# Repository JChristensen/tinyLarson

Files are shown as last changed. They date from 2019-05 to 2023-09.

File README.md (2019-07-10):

# Tiny Larson Scanner
https://github.com/JChristensen/tinyLarson  
README file  
Jack Christensen  
May-2019

## License
  
Tiny Larson Scanner by Jack Christensen is licensed under a [Creative Commons Attribution-ShareAlike 4.0 International License](http://creativecommons.org/licenses/by-sa/4.0/).

## Overview
This is just a fun project which is designed to utilize remaining capacity in old batteries while adding some decorative [Blinkenlights](https://en.wikipedia.org/wiki/Blinkenlights) to your shop or office.

Many battery-powered devices complain of low battery when there is still significant usable capacity left in the cells. Such cells can often power this circuit for many days or even a few weeks as the circuit only requires a few milliamperes and utilizes a boost regulator to maintain a constant supply voltage.

The circuit board fits on a dual AA cell holder and also has screw terminals for connection to other sources of power.

For more information, see the [firmware here](https://github.com/JChristensen/larson84).  
PC boards can be ordered from [OSH Park](https://oshpark.com/shared_projects/H8Wv3avv).  
A bill of materials is available at [Mouser Electronics](https://www.mouser.com/ProjectManager/ProjectDetail.aspx?AccessID=ef0590339b) and also in this repo.  

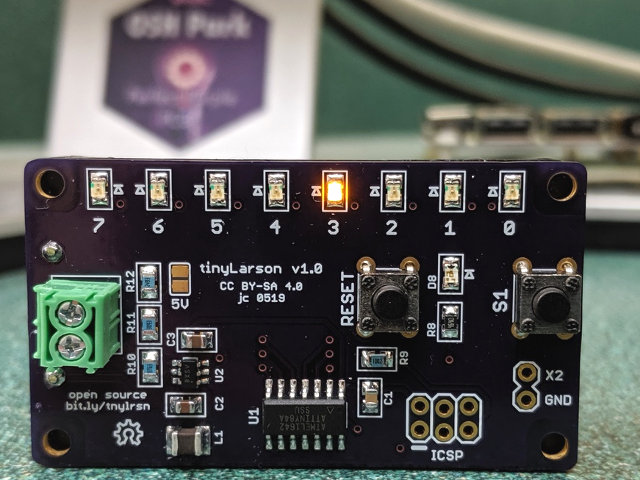
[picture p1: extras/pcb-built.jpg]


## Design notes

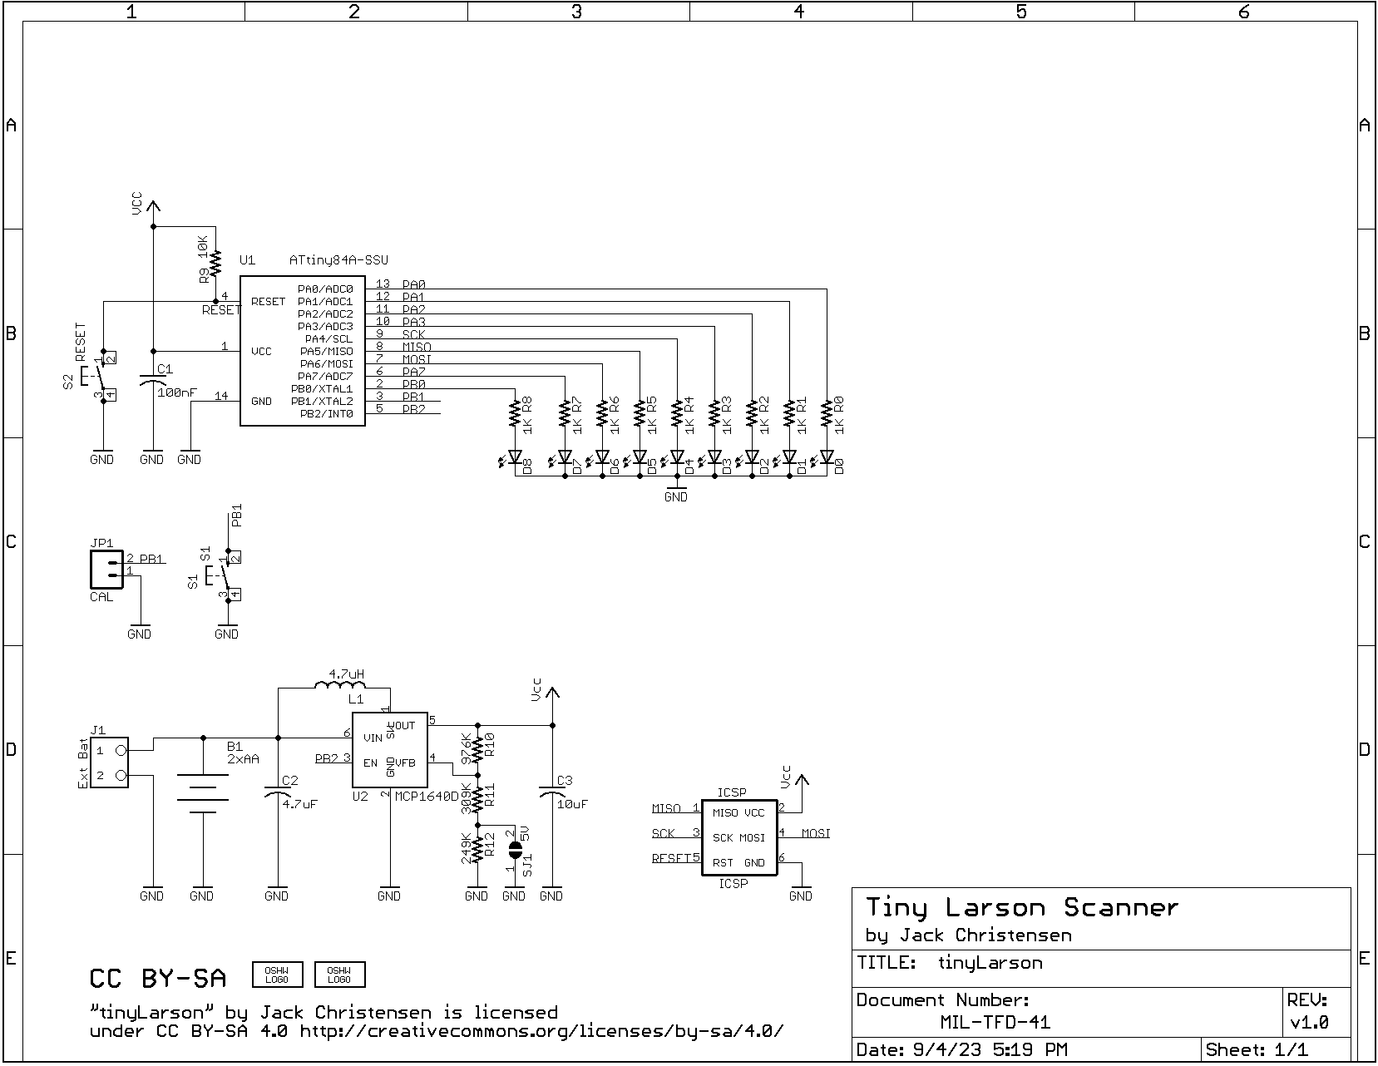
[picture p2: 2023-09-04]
schematic.png

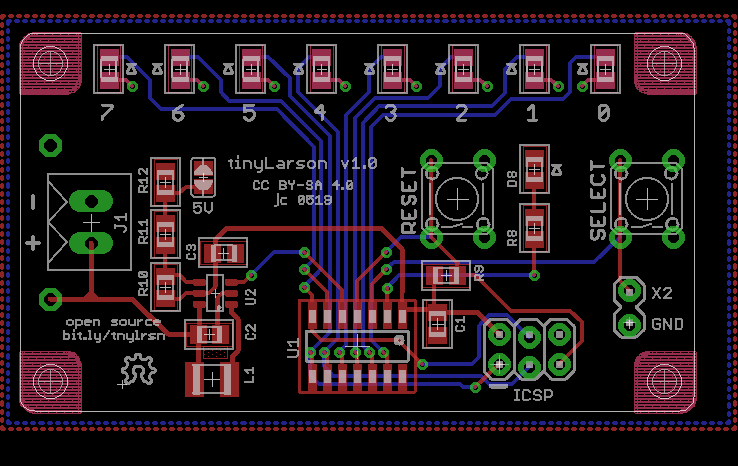
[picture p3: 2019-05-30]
board.png

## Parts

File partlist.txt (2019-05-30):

Partlist

Exported from tinyLarson.sch at 5/30/2019 3:46 PM

EAGLE Version 7.5.0 Copyright (c) 1988-2015 CadSoft

Assembly variant: 

Part     Value          Device                Package           Library  Sheet

B1       2xAA           BATTERY-2AAEAGLE      EAGLE-12BH321P-GR _jc      1
C1       100nF          C-USM0805             M0805             _jc      1
C2       4.7uF          C-USM0805             M0805             _jc      1
C3       10uF           C-USM0805             M0805             _jc      1
D0       Yel            LEDD0805A             D0805A            _jc      1
D1       Yel            LEDD0805A             D0805A            _jc      1
D2       Yel            LEDD0805A             D0805A            _jc      1
D3       Yel            LEDD0805A             D0805A            _jc      1
D4       Yel            LEDD0805A             D0805A            _jc      1
D5       Yel            LEDD0805A             D0805A            _jc      1
D6       Yel            LEDD0805A             D0805A            _jc      1
D7       Yel            LEDD0805              D0805             _jc      1
D8       Red            LEDD0805              D0805             _jc      1
ICSP     ICSP           AVR_SPI_PRG_62X3_LOCK 2X3_LOCK          _jc      1
J1       Ext Bat        OST-TB-23.5MM         OST-TB-2-3.5MM    _jc      1
JP1      CAL            M02LOCK               1X02_LOCK         SparkFun 1
L1       4.7uH          INDUCTORC1210K        C1210K            _jc      1
R0       1K             R-US_M0805            M0805             _jc      1
R1       1K             R-US_M0805            M0805             _jc      1
R2       1K             R-US_M0805            M0805             _jc      1
R3       1K             R-US_M0805            M0805             _jc      1
R4       1K             R-US_M0805            M0805             _jc      1
R5       1K             R-US_M0805            M0805             _jc      1
R6       1K             R-US_M0805            M0805             _jc      1
R7       1K             R-US_M0805            M0805             _jc      1
R8       1K             R-US_M0805            M0805             _jc      1
R9       10K            R-US_M0805            M0805             _jc      1
R10      976K           R-US_M0805            M0805             _jc      1
R11      309K           R-US_M0805            M0805             _jc      1
R12      249K           R-US_M0805            M0805             _jc      1
S1       S1             10-XXOCT              B3F-10XXOCT       _jc      1
S2       RESET          10-XXOCT              B3F-10XXOCT       _jc      1
SJ1      5V             SJ                    SJ                jumper   1
U1       ATtiny84A-SSU  ATTINYX4SO14          SO14              _jc      1
U2       MCP1640D       MCP1640               SOT23-6           _jc      1

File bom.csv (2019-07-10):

Bill of Materials
Tiny Larson Scanner
by Jack Christensen
May-2019
https://www.mouser.com/ProjectManager/ProjectDetail.aspx?AccessID=ef0590339b
Part | Qty | Mouser # | Description | Mfr. # | Manufacturer
B1 | 1 | 12BH321P-GR | Cylindrical Battery Contacts, Clips, Holders & Springs 2 "AA" PC LEADS BLK | 12BH321P-GR | Eagle Plastic Devices
C1 | 1 | 581-08053C104K | Multilayer Ceramic Capacitors MLCC - SMD/SMT 25V .1uF X7R 0805 10%TOL | 08053C104KAT2A | AVX
C2 | 1 | 963-EMK212ABJ475KG-T | Multilayer Ceramic Capacitors MLCC - SMD/SMT 0805 16VDC 4.7uF 10% X5R | EMK212ABJ475KG-T | Taiyo Yuden
C3 | 1 | 963-LMK212BJ106KG-T | Multilayer Ceramic Capacitors MLCC - SMD/SMT 10uF 10V X5R +/-10% 0805 Gen Purp | LMK212BJ106KG-T | Taiyo Yuden
D0-D7 | 8 | 859-LTST-C171KSKT | Standard LEDs - SMD Yellow Clear 587nm | LTST-C171KSKT | Lite-On
D8 | 1 | 859-LTST-C171KRKT | Standard LEDs - SMD Red Clear 55MCD | LTST-C171KRKT | Lite-On
J1 | 1 | 651-1984617 | Fixed Terminal Blocks PT 1.5/2-3.5H 2POS HRZ 3.5mm SCREW | 1984617 | Phoenix Contact
L1 | 1 | 963-CBC3225T4R7MR | Fixed Inductors 1210 4.7uH 130mOhms +/-20% 1010mA HiCur | CBC3225T4R7MR | Taiyo Yuden
R0-R8 | 9 | 603-RC0805FR-071KL | Thick Film Resistors - SMD 1K OHM 1% | RC0805FR-071KL | Yageo
R10 | 1 | 660-RK73H2ATTD9763F | Thick Film Resistors - SMD 1/4W 976K OHM 1% | RK73H2ATTD9763F | KOA Speer
R11 | 1 | 660-RK73H2ATTD3093F | Thick Film Resistors - SMD 1/4W 309K OHM 1% | RK73H2ATTD3093F | KOA Speer
R12 | 1 | 660-RK73H2ATTD2493F | Thick Film Resistors - SMD 1/4W 249K OHM 1% | RK73H2ATTD2493F | KOA Speer
R9 | 1 | 603-RC0805FR-1310KL | Thick Film Resistors - SMD 10K OHM 1% | RC0805FR-1310KL | Yageo
S1-S2 | 2 | 653-B3F-1020 | Tactile Switches 6X6 Flat 5mm Btn Force 100g w/o Grd | B3F-1020 | Omron
U1 | 1 | 556-ATTINY84A-SSU | 8-bit Microcontrollers - MCU 20MHz Ind. Grade | ATTINY84A-SSU | Microchip
U2 | 1 | 579-MCP1640DT-I/CHY | Switching Voltage Regulators 500 kHz 300 mA Syn Boost Converter | MCP1640DT-I/CHY | Microchip

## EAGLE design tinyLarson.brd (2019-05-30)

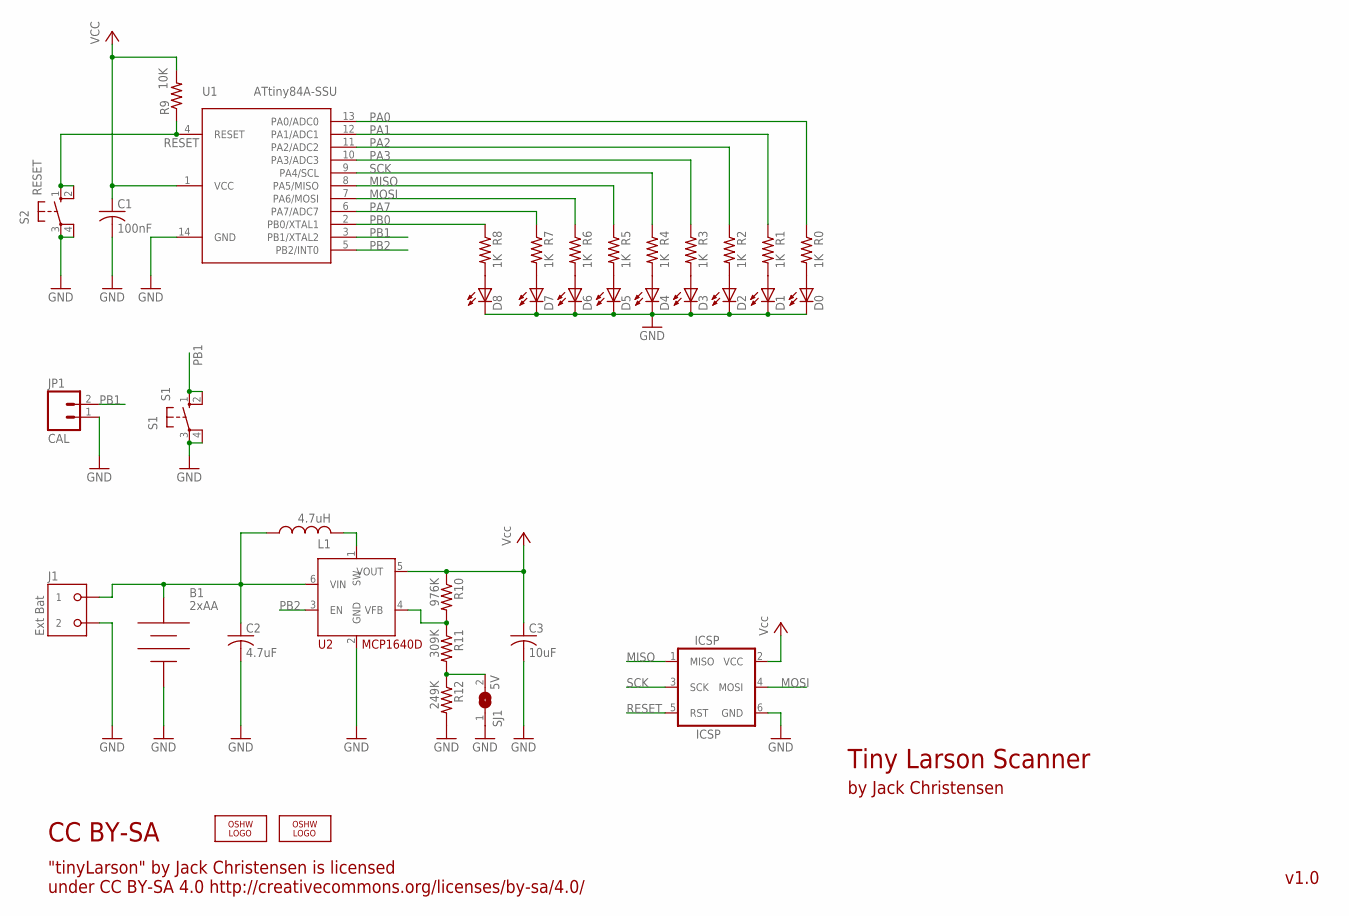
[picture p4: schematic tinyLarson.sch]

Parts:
B1: 2xAA; EAGLE-12BH321P-GR
C1: 100nF; M0805
C2: 4.7uF; M0805
C3: 10uF; M0805
D0, D1, D2, D3, D4, D5, D6: Yel; D0805A
D7: Yel; D0805
D8: Red; D0805
ICSP: ICSP; 2X3_LOCK
J1: Ext Bat; OST-TB-2-3.5MM
JP1: CAL; 1X02_LOCK
L1: 4.7uH; C1210K
LOGO1, LOGO2: OSHW_LOGO_8MILX0100-NT; OSHW_8X100_NOTEXT
R0, R1, R2, R3, R4, R5, R6, R7, R8: 1K; M0805
R9: 10K; M0805
R10: 976K; M0805
R11: 309K; M0805
R12: 249K; M0805
S1: S1; B3F-10XXOCT
S2: RESET; B3F-10XXOCT
SJ1: 5V; SJ
U1: ATtiny84A-SSU; SO14
U2: MCP1640D; SOT23-6

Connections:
GND: B1.NEG, C1.2, C2.2, C3.2, D0.K (C), D1.K (C), D2.K (C), D3.K (C), D4.K (C), D5.K (C), D6.K (C), D7.K (C), D8.K (C), ICSP.6 (GND), J1.P$2 (2), JP1.1, R12.2, S1.3, S1.4 (P1), S2.3, S2.4 (P1), SJ1.1, U1.14 (GND), U2.2 (GND)
MISO: ICSP.1 (MISO), R5.1, U1.8 (PA5/MISO)
MOSI: ICSP.4 (MOSI), R6.1, U1.7 (PA6/MOSI)
unnamed: R11.2, R12.1, SJ1.2
unnamed: R10.2, R11.1, U2.4 (VFB)
unnamed: D0.A, R0.2
unnamed: D1.A, R1.2
unnamed: D2.A, R2.2
unnamed: D3.A, R3.2
unnamed: L1.2, U2.1 (SW)
unnamed: D4.A, R4.2
unnamed: D5.A, R5.2
unnamed: D6.A, R6.2
unnamed: B1.POS, C2.1, J1.P$1 (1), L1.1, U2.6 (VIN)
unnamed: D7.A, R7.2
unnamed: D8.A, R8.2
PA0: R0.1, U1.13 (PA0/ADC0)
PA1: R1.1, U1.12 (PA1/ADC1)
PA2: R2.1, U1.11 (PA2/ADC2)
PA3: R3.1, U1.10 (PA3/ADC3)
PA7: R7.1, U1.6 (PA7/ADC7)
PB0: R8.1, U1.2 (PB0/XTAL1)
PB1: JP1.2, S1.1 (S), S1.2 (S1), U1.3 (PB1/XTAL2)
PB2: U1.5 (PB2/INT0), U2.3 (EN)
RESET: ICSP.5 (RST), R9.1, S2.1 (S), S2.2 (S1), U1.4 (RESET)
SCK: ICSP.3 (SCK), R4.1, U1.9 (PA4/SCL)
VCC: C1.1, C3.1, ICSP.2 (VCC), R9.2, R10.1, U1.1 (VCC), U2.5 (VOUT)

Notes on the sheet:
"tinyLarson" by Jack Christensen is licensed under CC BY-SA 4.0 http://creativecommons.org/licenses/by-sa/4.0/
CC BY-SA
Tiny Larson Scanner
by Jack Christensen
v1.0

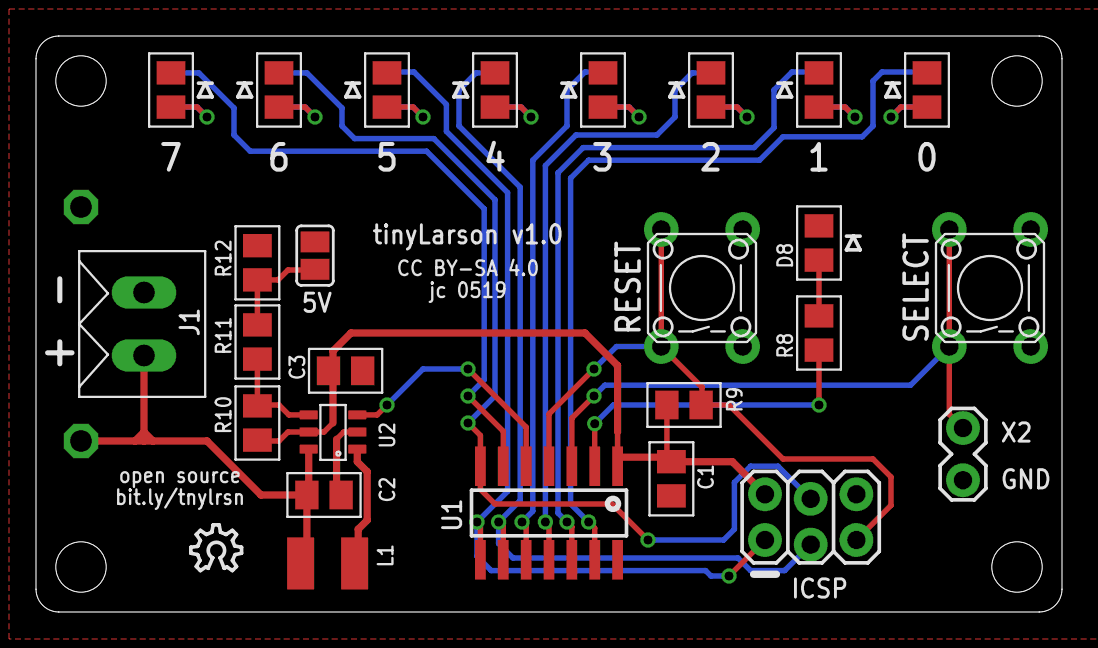
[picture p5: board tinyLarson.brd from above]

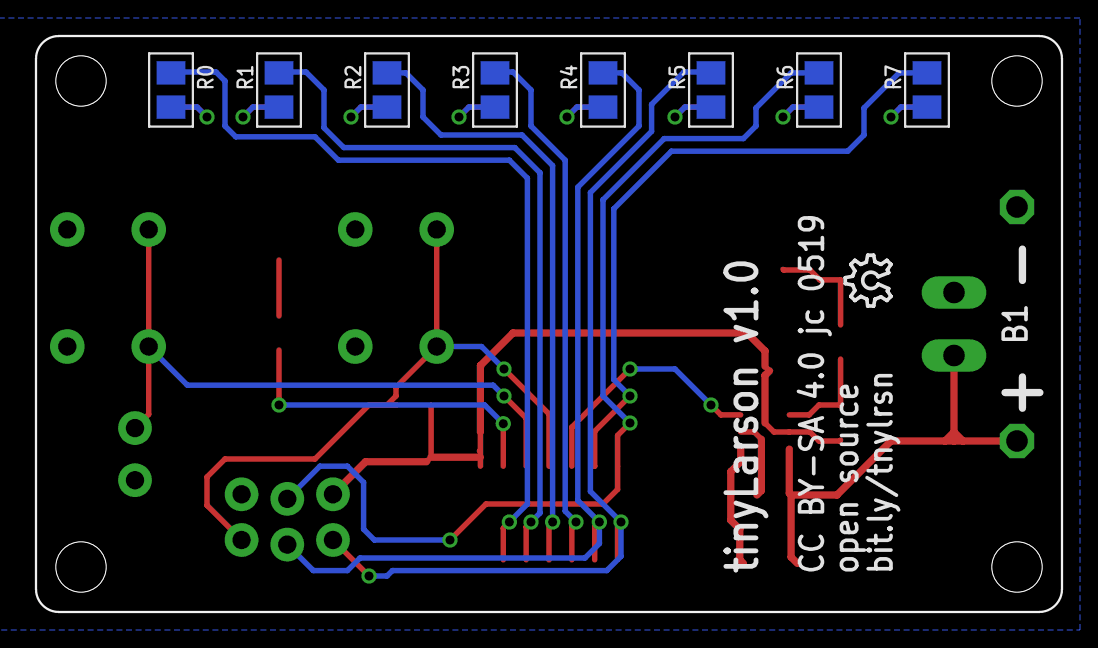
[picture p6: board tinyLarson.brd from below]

Board: 2 copper layers, 57.0 x 32.0 mm, 37 parts (10 on the bottom side), 27 nets.

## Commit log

2019-05-23 Initial commit.
    [tinyLarson.brd, tinyLarson.sch]
2019-05-30 Add images.
    [tinyLarson.brd, tinyLarson.sch]
2019-07-10 Add README, LICENSE, BOM, photo.
    [bom.csv, bom.ods]
2023-09-04 Update schematic document number.
    [tinyLarson.sch]

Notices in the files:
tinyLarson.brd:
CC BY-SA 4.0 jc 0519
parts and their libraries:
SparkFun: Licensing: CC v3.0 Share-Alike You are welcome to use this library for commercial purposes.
